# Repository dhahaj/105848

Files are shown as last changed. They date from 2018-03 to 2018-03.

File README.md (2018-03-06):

# 105848 - Tester Control PCB

[][releases]
[][commits]
[][detex]

### IDE: Altium Designer 18
### Revision: D4
### Date: 3/5/2018

[releases]: https://github.com/dhahaj/105848/releases
[releases-shield]: https://img.shields.io/github/release/hassio-addons/addon-appdaemon3.svg
[commits]: https://github.com/dhahaj/105848/commits/master
[commits-shield]: https://img.shields.io/github/commit-activity/y/hassio-addons/addon-ide.svg
[last-commit]: https://img.shields.io/github/last-commit/google/skia/infra/config.svg?style=flat-square
[last-commit-shield]: https://img.shields.io/github/last-commit/google/skia.svg
[repository]: https://github.com/dhahaj/105848/repository
[size-shield]: https://img.shields.io/github/repo-size/badges/shields.svg
[detex]: https://detex.com

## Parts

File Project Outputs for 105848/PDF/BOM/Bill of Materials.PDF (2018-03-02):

Designator | Quantit y | Value | MPN | Description | Comment | Manufacturer | PackageRefer ence
BR1 | 1 | 1A SMT Bridge Rectifier | | 1A SMT Bridge Rectifier | BRIDGE - SMT
C1 | 1 | 220uF | | Capacitor TO - 200 SPACING | Capacitor - Thru-Hole
C2, C6, C7 | 3 | 0.1uF | | 1206 Ceramic Capacitor | 1206 Capacitor | | 1206
C3, C4 | 2 | 1uF | | 1206 Ceramic Capacitor | 1206 Capacitor | | 1206
C5, C8 | 2 | 0.33uF | | 1206 Ceramic Capacitor | 1206 Capacitor | | 1206
C9 | 1 | 100uF | | Capacitor TO - 200 SPACING | Capacitor - Thru-Hole
D1, D2, D10 | 3 | Diode 1N5400 | B5819W | 1N5400, Diode, SMD | Diode SMT, 1N4002
D3 | 1 | SS12 | SS12 | Schottky Diode, SMD | SS12 | | SMA
D4, D5, D6, D7, D8, D9 | 6 | 1N4002 | B5819W | Diode, SMD | 1N4002
F1 | 1 | 1A fuse | | FUSE_200 | THERMAL FUSE 1A
IC1 | 1 | ULN2003A | ULN2003A | ULN2003 | ULN2003A
IC2 | 1 | ILD207T | ILD207T | DUAL OPTO ISOLATOR | OPTO ISOLATOR
J1 | 1 | KLD-0202_2 | DC-005 | DC POWER PLUG | DC Power Jack
J2 | 1 | TECO-5520470-3_V | TECO-5520470-3_V | 6 Position Modular Jack Connector | 6P MOD JACK | Tetco
J3, J4, J5, J6 | 4 | JUMPER_2 | | JUMPER_2 | PWR IND, RESET, TEST IND, QW PWR
J7, J8, J9, J10 | 4 | JMP_3PIN | | JMP_3PIN | JMP_3PIN
JP1 | 1 | 8x2_HEADER | | Ribbon Cable Connection | 8x2_HEADER
JP2 | 1 | ICSP | P125-1106A1BS116A1 | DIP-BLACK-MALE-HEADER(6P-2.54) | ICSP
K1, K2, K3, K4 | 4 | AZ850-5 | AZ850-5 | AZ850-5 | AC PWR, QW, RELAY1, RELAY2 | Zetler
LED1, LED2, LED3, LED4 | 4 | LED-0805 | 17-215SURC/S530-A2/TR8 | 12V Power Indicator, Battery Power Indicator, 5V Power Indicator, Power Input Indicator | 12V, BATT, 5V, VIN | | 0805
P1 | 1 | Arduino Uno | | Arduino Uno | Arduino Uno | Arduino.cc
P2 | 1 | Metro Mini 328 | 2590 | Adafruit METRO Mini 328 rev A | Metro Mini 328 | Adafruit Industries
Q1 | 1 | MMBT2222 | MMBT2222 | NPN Bipolar Transistor | MMBT2222 | | SOT-23
Q2, Q3 | 2 | 2N7002 | 2N7002 | N-Channel Enhancement Mode FET | 2N7002 | | SOT-23
R1, R5 | 2 | 20K | | RESISTOR, SMD, 1206 | Resistor | | 1206
R2 | 1 | 500R | | RESISTOR, SMD, 1206 | Resistor | | 1206
R3 | 1 | 100K | | RESISTOR, SMD, 1206 | Resistor | | 1206
R4, R9, R11, R12 | 4 | 1k | | RESISTOR, SMD, 1206 | Resistor | | 1206
R6 | 1 | 2K | | RESISTOR, SMD, 1206 | Resistor | | 1206
R7, R10, R13 | 3 | 2.2K | | RESISTOR, SMD, 1206 | Resistor | | 1206
R8 | 1 | 3.74K | | RESISTOR, SMD, 1206 | Resistor | | 1206
U1 | 1 | DMG3415U | DMG3415U | MOSFET P-CHANNEL | MOSFET P-CHANNEL | Diodes, Inc. | SOT-23
VR1 | 1 | LM317 | LM317DCYR | Adjustable SMT Voltage Regulator | LM317DCYR | TI | SOT-23-4
VR2 | 1 | MC7812CD2TG | MC7812CD2TG | SMT 12V Fixed Output Voltage Regulator | MC7812 | ON Semi | DPAK
VR3 | 1 | MC7805BDTRKG | MC7805BDTRKG | SMT 5V Linear Voltage Regulator | MC7805 | ON Semi | DPAK-3

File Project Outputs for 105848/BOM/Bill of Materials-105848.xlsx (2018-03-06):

Designator | Quantity | Value | Description | Comment | PackageDescription
BR1 | 1 | 1A SMT Bridge Rectifier | 1A SMT Bridge Rectifier | BRIDGE - SMT
C1 | 1 | 220uF | Capacitor TO - 200 SPACING | Capacitor - Thru-Hole
C2, C6, C7 | 3 | 0.1uF | 1206 Ceramic Capacitor | 1206 Capacitor | 1206
C3, C4 | 2 | 1uF | 1206 Ceramic Capacitor | 1206 Capacitor | 1206
C5, C8 | 2 | 0.33uF | 1206 Ceramic Capacitor | 1206 Capacitor | 1206
C9 | 1 | 100uF | Capacitor TO - 200 SPACING | Capacitor - Thru-Hole
D1, D2, D9, D10 | 4 | BAS20 | BAS20, Diode, SMD | BAS20 | SOT-23
D3 | 1 | SS12 | Schottky Diode, SMD | SS12 | SMB
D4, D5, D6, D7, D8 | 5 | 1N4002 | Diode, SMD | 1N4002 | SMB
F1 | 1 | 1A fuse | FUSE_200 | THERMAL FUSE 1A
IC1 | 1 | ULN2003A | ULN2003 | ULN2003A | SO-16
IC2 | 1 | ILD207T | DUAL OPTO ISOLATOR | ILD207 | SO8
J1 | 1 | KLD-0202_2 | DC POWER PLUG | DC Power Jack
J2 | 1 | TECO-5520470-3_V | 6 Position Modular Jack Connector | 6P MOD JACK
J3, J4, J5, J6 | 4 | JUMPER_2 | JUMPER_2 | PWR IND, RESET, TEST IND, QW PWR
J7, J8, J9, J10 | 4 | JMP_3PIN | JMP_3PIN | JMP_3PIN
JP1 | 1 | 8x2_HEADER | Ribbon Cable Connection | 8x2_HEADER
JP2 | 1 | ICSP | DIP-BLACK-MALE-HEADER(6P-2.54) | ICSP
K1, K2, K3, K4 | 4 | AZ850-5 | AZ850-5 | AC PWR, QW, RELAY1, RELAY2
LED1, LED2, LED3, LED4 | 4 | LED-0805 | 12V Power Indicator, Battery Power Indicator, 5V Power Indicator, Power Input Indicator | 12V, BATT, 5V, VIN | 0805
P1 | 1 | Arduino Uno | Arduino Uno | Arduino Uno
P2 | 1 | Metro Mini 328 | Adafruit METRO Mini 328 rev A | Metro Mini 328
Q1 | 1 | MMBT2222 | NPN Bipolar Transistor | MMBT2222 | SOT-23
Q2, Q3 | 2 | 2N7002 | N-Channel Enhancement Mode FET | 2N7002 | SOT-23
R1, R5 | 2 | 20K | RESISTOR, SMD, 1206 | Resistor | 1206
R2 | 1 | 500R | RESISTOR, SMD, 1206 | Resistor | 1206
R3 | 1 | 100K | RESISTOR, SMD, 1206 | Resistor | 1206
R4, R9, R11, R12 | 4 | 1k | RESISTOR, SMD, 1206 | Resistor | 1206
R6 | 1 | 2K | RESISTOR, SMD, 1206 | Resistor | 1206
R7, R10 | 2 | 2.2K | RESISTOR, SMD, 1206 | Resistor | 1206
R8 | 1 | 3.74K | RESISTOR, SMD, 1206 | Resistor | 1206
R13 | 1 | 3.3k | RESISTOR, SMD, 1206 | Resistor | 1206
U1 | 1 | DMG3415U | MOSFET P-CHANNEL | MOSFET P-CHANNEL | SOT-23
VR1 | 1 | LM317DCYR | Adjustable SMT Voltage Regulator | LM317DCYR | SOT-23-4
VR2 | 1 | MC7812CD2TG | SMT 12V Fixed Output Voltage Regulator | MC7812CD | DPAK
VR3 | 1 | MC7805BDTRKG | SMT 5V Linear Voltage Regulator | MC7805BDT | DPAK-3

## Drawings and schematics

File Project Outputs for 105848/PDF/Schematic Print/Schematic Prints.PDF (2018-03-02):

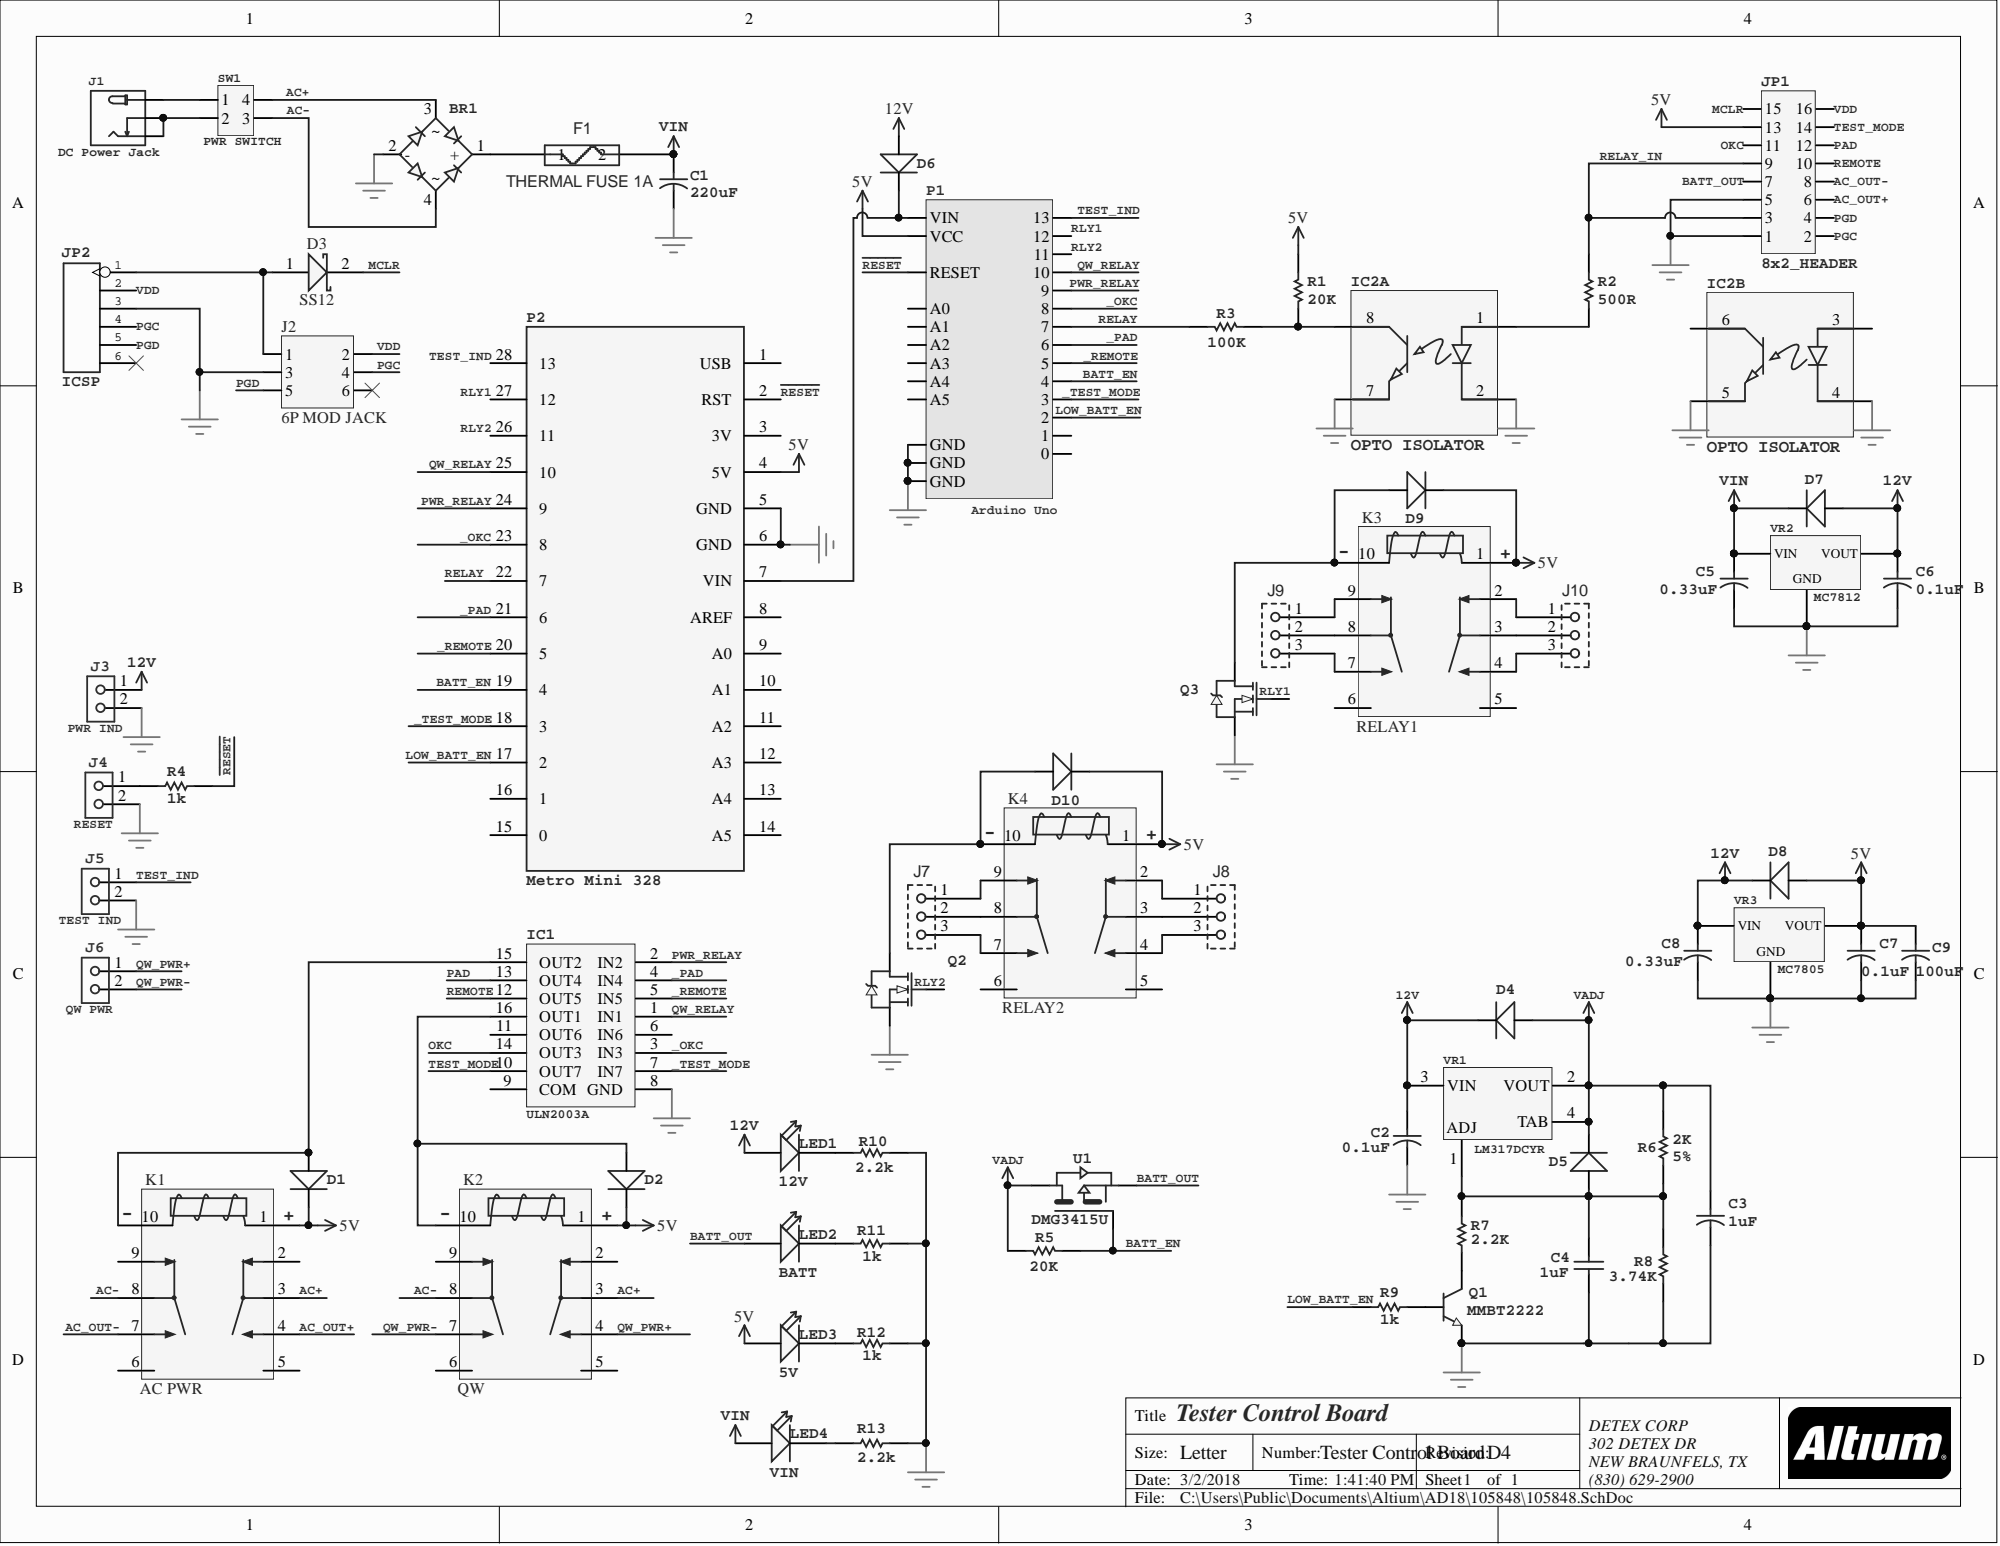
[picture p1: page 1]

VOUT TAB ADJ | 2 VIN 3

Tester Control Board Title | DETEX CORP 302 DETEX DR NEW BRAUNFELS, TX (830) 629-2900

Size: Letter | Number: Tester Control BoardD4 | Revision:
Date: 3/2/2018 Time: 1:41:40 PM | | Sheet 1 of 1

C:\Users\Public\Documents\Altium\AD18\105848\105848.SchDoc

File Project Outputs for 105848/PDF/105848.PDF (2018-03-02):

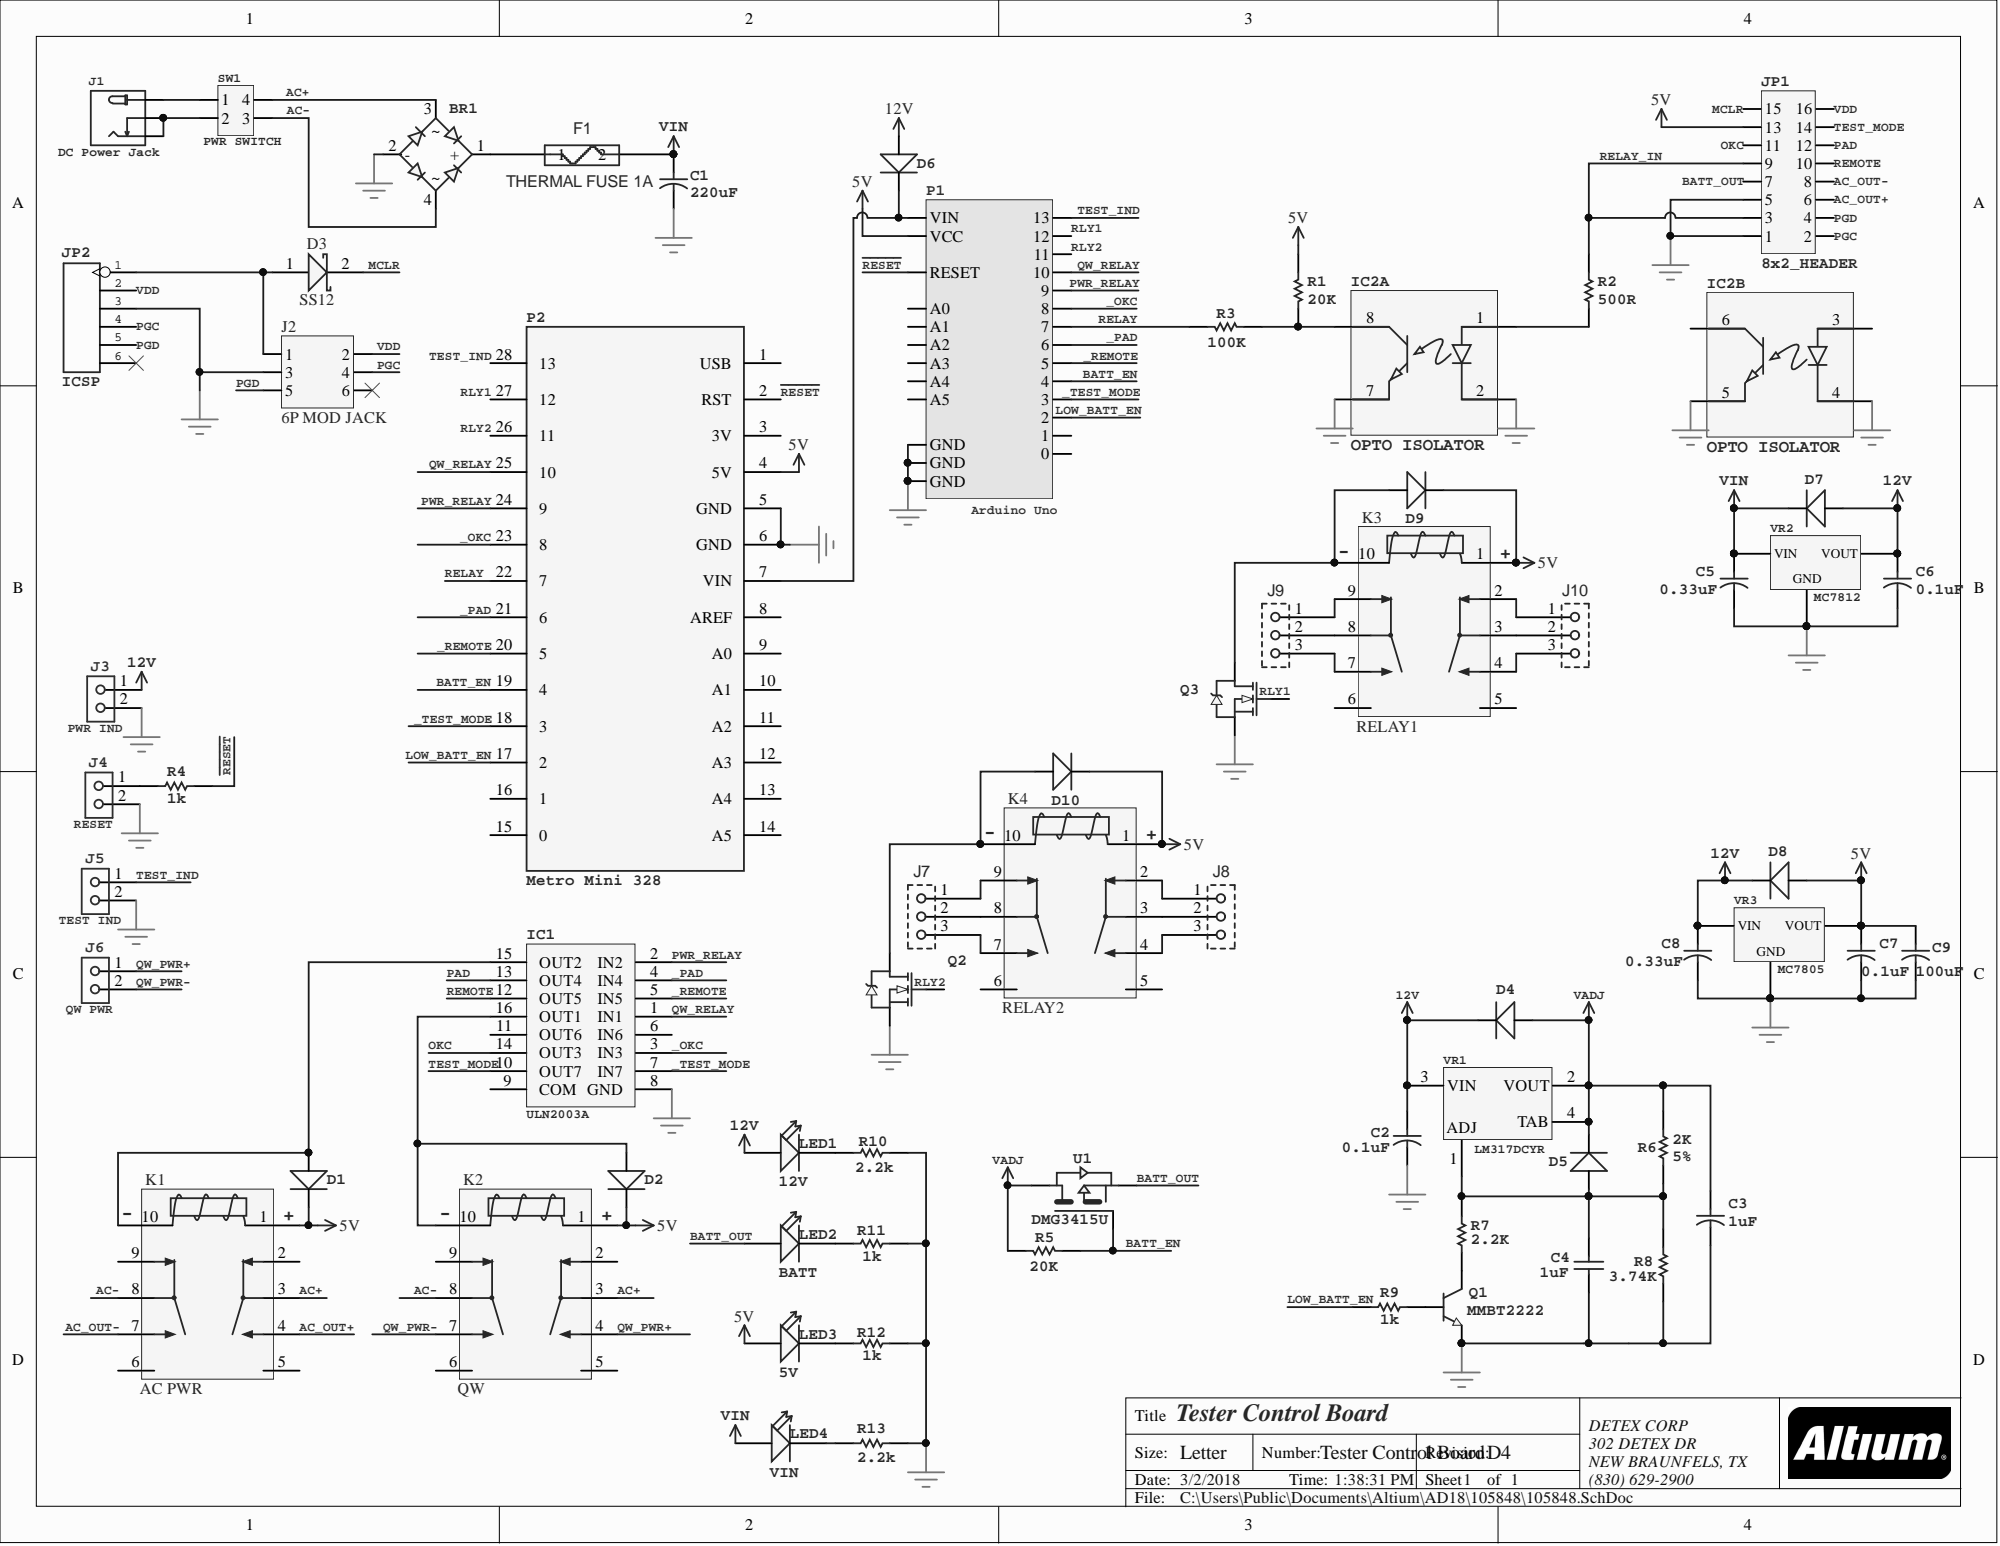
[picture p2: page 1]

VOUT TAB ADJ | 2 VIN 3

Tester Control Board Title | DETEX CORP 302 DETEX DR NEW BRAUNFELS, TX (830) 629-2900

Size: Letter | Number: Tester Control BoardD4 | Revision:
Date: 3/2/2018 Time: 1:38:31 PM | | Sheet 1 of 1

C:\Users\Public\Documents\Altium\AD18\105848\105848.SchDoc

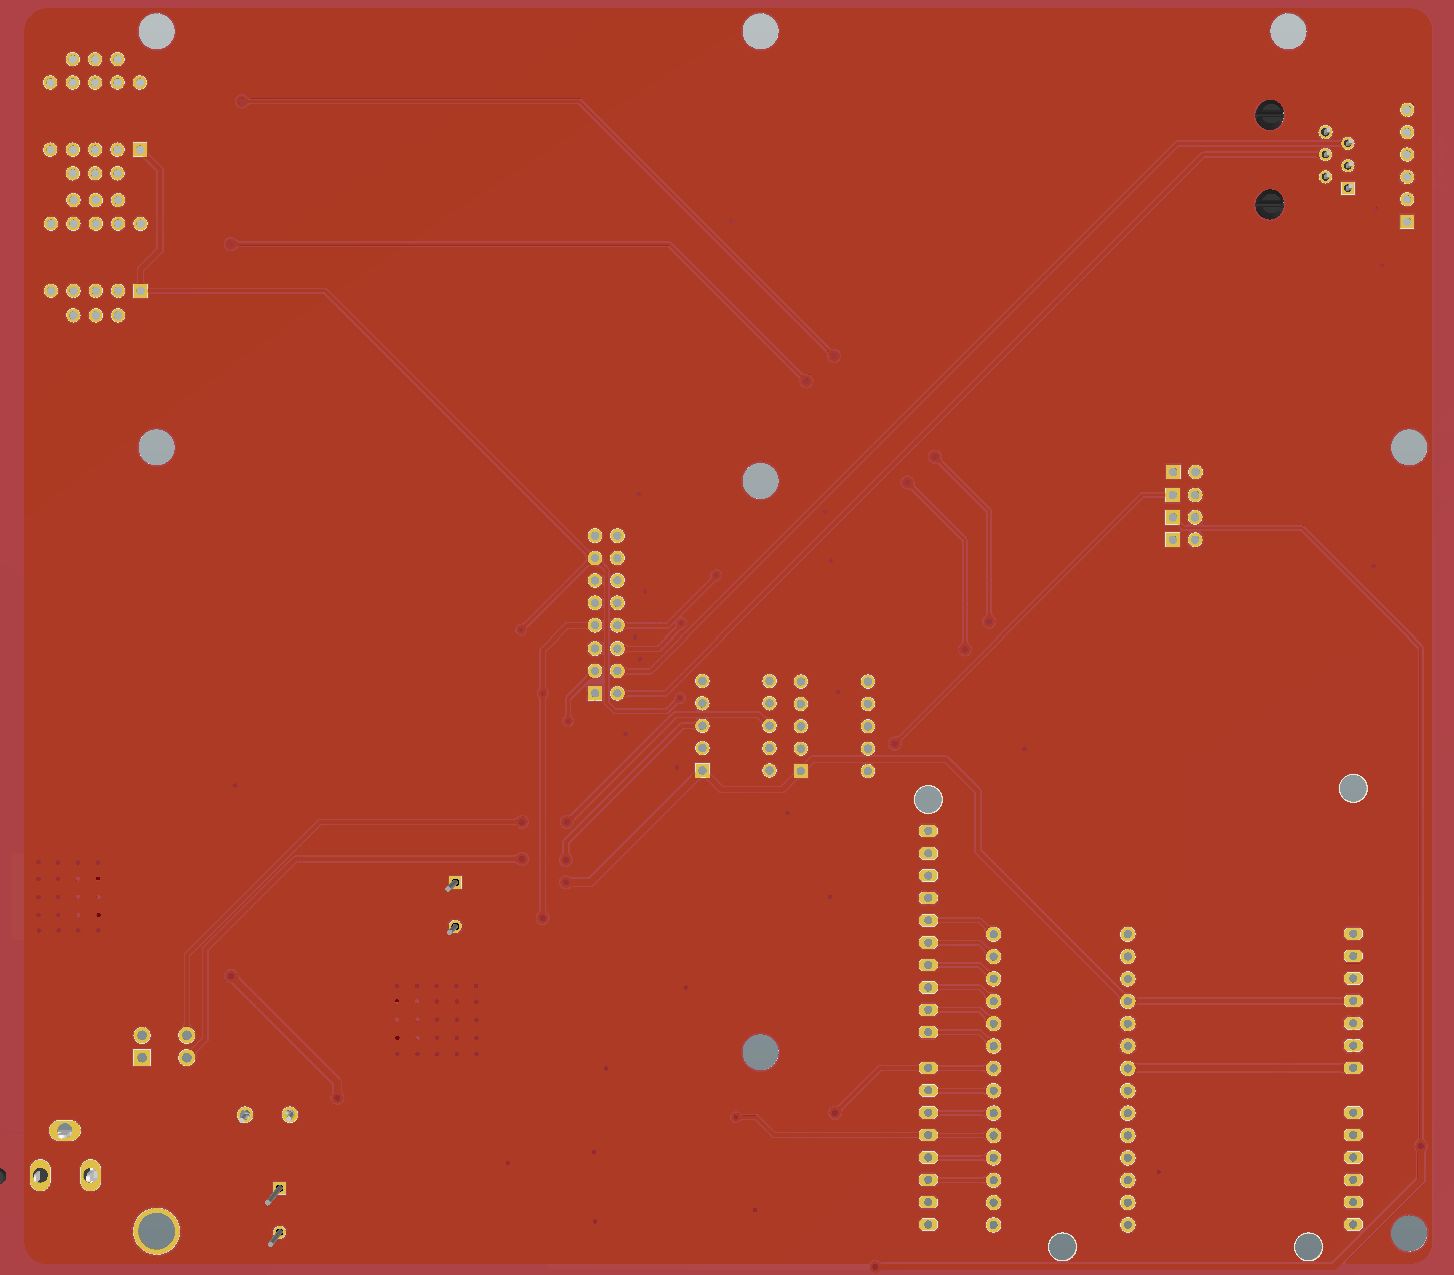
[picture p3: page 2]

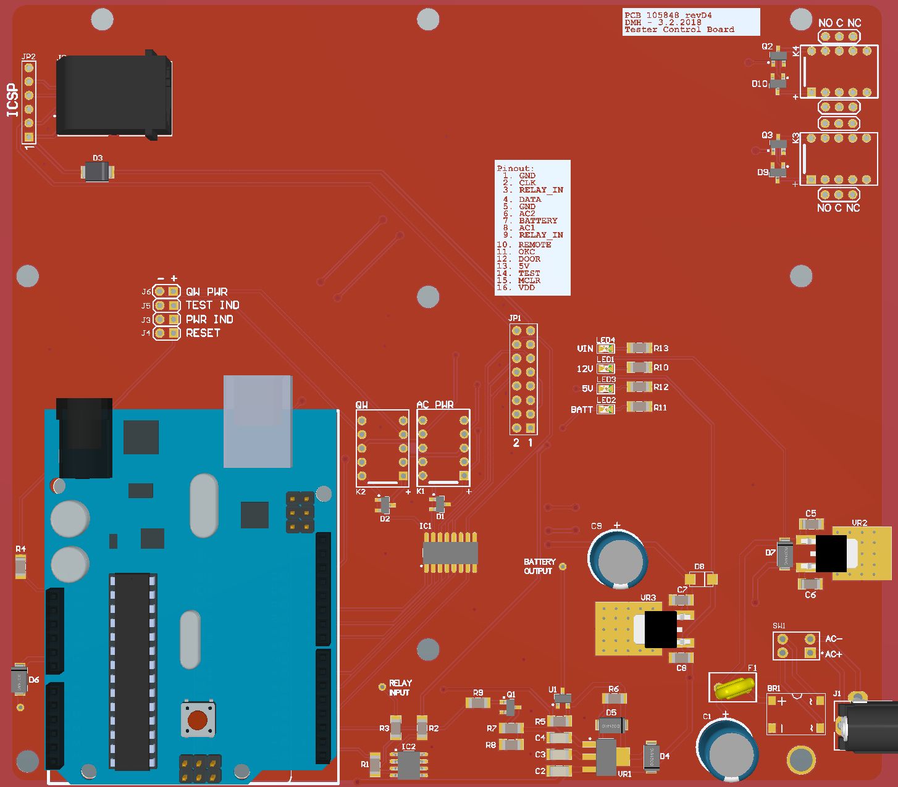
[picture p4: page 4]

Designator | Quantit y | Value | MPN | Description | Comment | Manufacturer | PackageRefer ence
BR1 | 1 | 1A SMT Bridge Rectifier | | 1A SMT Bridge Rectifier | BRIDGE - SMT
C1 | 1 | 220uF | | Capacitor TO - 200 SPACING | Capacitor - Thru-Hole
C2, C6, C7 | 3 | 0.1uF | | 1206 Ceramic Capacitor | 1206 Capacitor | | 1206
C3, C4 | 2 | 1uF | | 1206 Ceramic Capacitor | 1206 Capacitor | | 1206
C5, C8 | 2 | 0.33uF | | 1206 Ceramic Capacitor | 1206 Capacitor | | 1206
C9 | 1 | 100uF | | Capacitor TO - 200 SPACING | Capacitor - Thru-Hole
D1, D2, D10 | 3 | Diode 1N5400 | B5819W | 1N5400, Diode, SMD | Diode SMT, 1N4002
D3 | 1 | SS12 | SS12 | Schottky Diode, SMD | SS12 | | SMA
D4, D5, D6, D7, D8, D9 | 6 | 1N4002 | B5819W | Diode, SMD | 1N4002
F1 | 1 | 1A fuse | | FUSE_200 | THERMAL FUSE 1A
IC1 | 1 | ULN2003A | ULN2003A | ULN2003 | ULN2003A
IC2 | 1 | ILD207T | ILD207T | DUAL OPTO ISOLATOR | OPTO ISOLATOR
J1 | 1 | KLD-0202_2 | DC-005 | DC POWER PLUG | DC Power Jack
J2 | 1 | TECO-5520470-3_V | TECO-5520470-3_V | 6 Position Modular Jack Connector | 6P MOD JACK | Tetco
J3, J4, J5, J6 | 4 | JUMPER_2 | | JUMPER_2 | PWR IND, RESET, TEST IND, QW PWR
J7, J8, J9, J10 | 4 | JMP_3PIN | | JMP_3PIN | JMP_3PIN
JP1 | 1 | 8x2_HEADER | | Ribbon Cable Connection | 8x2_HEADER
JP2 | 1 | ICSP | P125-1106A1BS116A1 | DIP-BLACK-MALE-HEADER(6P-2.54) | ICSP
K1, K2, K3, K4 | 4 | AZ850-5 | AZ850-5 | AZ850-5 | AC PWR, QW, RELAY1, RELAY2 | Zetler
LED1, LED2, LED3, LED4 | 4 | LED-0805 | 17-215SURC/S530-A2/TR8 | 12V Power Indicator, Battery Power Indicator, 5V Power Indicator, Power Input Indicator | 12V, BATT, 5V, VIN | | 0805
P1 | 1 | Arduino Uno | | Arduino Uno | Arduino Uno | Arduino.cc
P2 | 1 | Metro Mini 328 | 2590 | Adafruit METRO Mini 328 rev A | Metro Mini 328 | Adafruit Industries
Q1 | 1 | MMBT2222 | MMBT2222 | NPN Bipolar Transistor | MMBT2222 | | SOT-23
Q2, Q3 | 2 | 2N7002 | 2N7002 | N-Channel Enhancement Mode FET | 2N7002 | | SOT-23
R1, R5 | 2 | 20K | | RESISTOR, SMD, 1206 | Resistor | | 1206
R2 | 1 | 500R | | RESISTOR, SMD, 1206 | Resistor | | 1206
R3 | 1 | 100K | | RESISTOR, SMD, 1206 | Resistor | | 1206
R4, R9, R11, R12 | 4 | 1k | | RESISTOR, SMD, 1206 | Resistor | | 1206
R6 | 1 | 2K | | RESISTOR, SMD, 1206 | Resistor | | 1206
R7, R10, R13 | 3 | 2.2K | | RESISTOR, SMD, 1206 | Resistor | | 1206
R8 | 1 | 3.74K | | RESISTOR, SMD, 1206 | Resistor | | 1206
U1 | 1 | DMG3415U | DMG3415U | MOSFET P-CHANNEL | MOSFET P-CHANNEL | Diodes, Inc. | SOT-23
VR1 | 1 | LM317 | LM317DCYR | Adjustable SMT Voltage Regulator | LM317DCYR | TI | SOT-23-4
VR2 | 1 | MC7812CD2TG | MC7812CD2TG | SMT 12V Fixed Output Voltage Regulator | MC7812 | ON Semi | DPAK
VR3 | 1 | MC7805BDTRKG | MC7805BDTRKG | SMT 5V Linear Voltage Regulator | MC7805 | ON Semi | DPAK-3



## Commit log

2018-02-19 first commit for the new revision PCB
    [105848.PcbDoc, 105848.PrjPCB, 105848.SchDoc]
2018-02-19 Added the essential components.
    [105848.PcbDoc, 105848.PrjPCB, 105848.SchDoc]
2018-02-20 Added database library
    [105848.PcbDoc, 105848.PrjPCB, 105848.SchDoc]
2018-02-20 Added additional libraries
    [105848_revD3.PcbLib, 105848_revD3_1.SCHLIB, Train2.PCBLIB]
2018-02-20 renamed local libraries. added additional components.
    [105848.PcbDoc, 105848.PcbLib, 105848.PrjPCB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]
2018-02-20 modified layout. added uno.
    [105848.PcbDoc]
2018-02-20 added arduino uno component
    [105848.SCHLIB]
2018-02-20 added arduino uno to project.
2018-02-21 Added battery circuit to schematic and board layout.
    [105848.PcbDoc, 105848.SchDoc]
2018-02-21 Added battery circuitry.
    [105848.PrjPCB]
2018-02-21 Modified DMG3415U Schematic Component
    [105848.SCHLIB]
2018-02-22 Modified Layout
    [105848.PcbDoc]
2018-02-22 Modified schematic
    [105848.SchDoc]
2018-02-22 Changed Layout, completed net connections
    [105848.PcbDoc]
2018-02-22 Changed VR1 schematic component, slight visual improvments.
    [105848.SchDoc]
2018-02-22 Modified a few components for correctness
    [105848.SCHLIB]
2018-02-22 Added ground planes. Connected relays to ac power.
    [105848.PcbDoc]
2018-02-22 Changed LED resistor values
    [105848.SchDoc]
2018-02-22 Added 12V Linear Voltage Regulator
    [105848.SCHLIB]
2018-02-23 Added 12V Regulator
    [105848.PcbDoc]
2018-02-23 Updated Project
    [105848.PrjPCB]
2018-02-23 Fixed diodes footprint pad names to match the schematic component. Fixed LED duplicate pins error on schematic component.
    [105848.SchDoc]
2018-02-23 Added thermal relief vias to the12V regulator to help dissipate heat. Added diode on Arduino Vin pin. Connected 5V trace to ribbon cable connector.
    [105848.PcbDoc]
2018-02-23 Fixed duplicate pins on LED footprint.
    [105848.SCHLIB]
2018-02-23 Fixed header descriptions. Added 5V regulator.
    [105848.SchDoc]
2018-02-23 Connected headers. Added 5V Regulator.
    [105848.PcbDoc]
2018-02-23 Fixed Arduino footprint to match Uno Rev 3 layout.
    [105848.SCHLIB]
2018-02-26 Fixed several components and added a few models.
    [105848.PcbLib]
2018-02-26 Relocated 12V Regulator. New ground pours. Labelled relays with description. Added thermal fuse on input power.
    [105848.PcbDoc]
2018-02-26 Add hole tolerances +-3 mils.
    [105848.PcbDoc]
2018-02-26 Add output job file to project.
    [105848.PrjPCB]
2018-02-26 Setup gerber outputs.
2018-02-26 Added gerber files
    [105848.GBL, 105848.GBO, 105848.GBP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]
2018-02-28 Added 2 additional relays, added backwards compatiablity with older designs using the adafruit metro mini.
    [105848.PcbDoc]
2018-02-28 Added D2PACK footprint.
    [105848.PcbLib]
2018-02-28 Added latest gerber and nc drill files from newest layout.
    [105848.GBL, 105848.GBS, 105848.GKO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]
2018-03-01 Added capacitor to 5V power. Created additional thermal via connections on GND pad for VR2 and VR3.
    [105848.SchDoc]
2018-03-01 Added 2N7002 component.
    [105848.SCHLIB]
2018-03-01 Modified D1, D2 footprints as SOT-23 diodes. Added back emf diodes on relay1, relay2.
2018-03-01 Included keepouts on the mounting holes for additonal backoff on the solder mask.
2018-03-01 Added reset connection on metro mini footprint.
    [105848.SchDoc]
2018-03-01 Added fab notes to drill drawing.
2018-03-01 Fixed 8x2 Ribbon Cable connector component.
    [105848.SCHLIB]
2018-03-01 Updated JP1 pinout. Fixed opto isolator orientation. Added headers to secondary relays.
    [105848.SchDoc]
2018-03-01 Added latest gerber exports.
    [105848.GBL, 105848.GBS, 105848.GKO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]
2018-03-01 Fixed ICSP RJ11 connector
2018-03-01 updated gerber exports.
    [105848.GBL, 105848.GBS, 105848.GTL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]
2018-03-02 Added silkscreen text for identifying the board. Fixed the ICSP RJ11 connector connections. Board sent out for fab.
2018-03-02 Final board prior to fab.
    [105848.GTO]
2018-03-02 Added exports for PDF's of the schematic, BOM, PCB board and a PDF3D model. Also added Excel export of the BOM and a 3D step file.
2018-03-02 Added component paramters for exporting a BOM.
    [105848.SchDoc]
2018-03-02 Added various project output files.
    [Bill of Materials-105848.xlsx]
2018-03-05 Modified MFR part numbers.
    [105848.SchDoc]
2018-03-06 Updated BOM.
    [Bill of Materials-105848.xlsx]
2018-03-09 Updated gerber file exports. Removed MySVNDatabaseLib_2.ldb.
    [105848.GBL, 105848.GBO, 105848.GBP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]
2018-06-04 Cleaned up schematic. Rearranged a few items.
    [105848.SchDoc]
2018-07-25 modified .gitignore
    removed Status Report.txt
    [Pick Place for 105848.csv]
